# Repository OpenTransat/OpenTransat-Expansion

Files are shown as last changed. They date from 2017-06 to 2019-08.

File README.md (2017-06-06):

# OpenTransat-Expansion

The [Navigator](https://github.com/OpenTransat/OpenTransat-Navigator) is mounted on top of Expansion Board that will provide additional functions more specific to the boat. This modular design allows to make quick modifications on the Expansion Board while keeping the more complex Navigation Board unchanged.

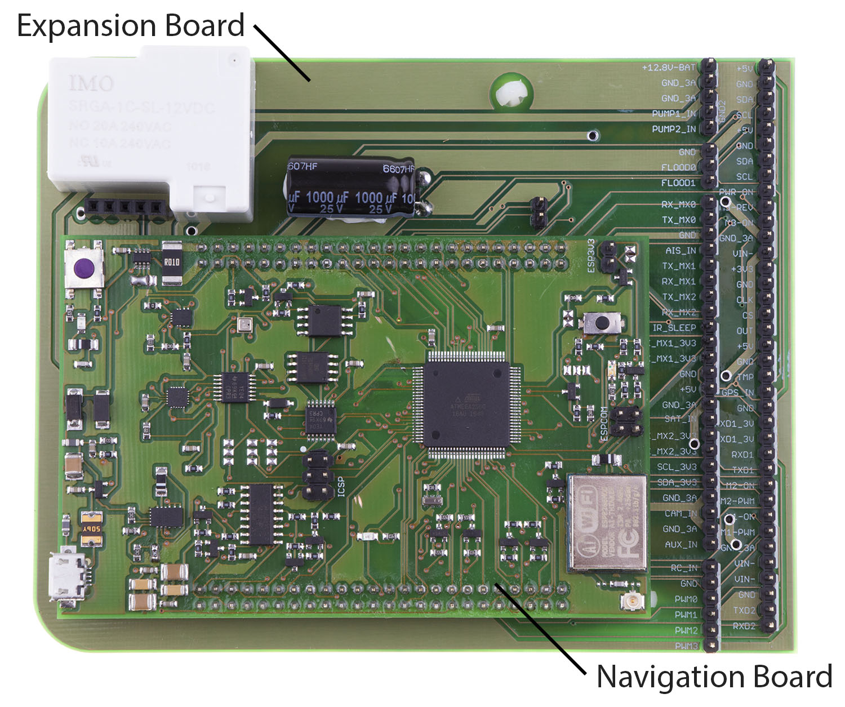
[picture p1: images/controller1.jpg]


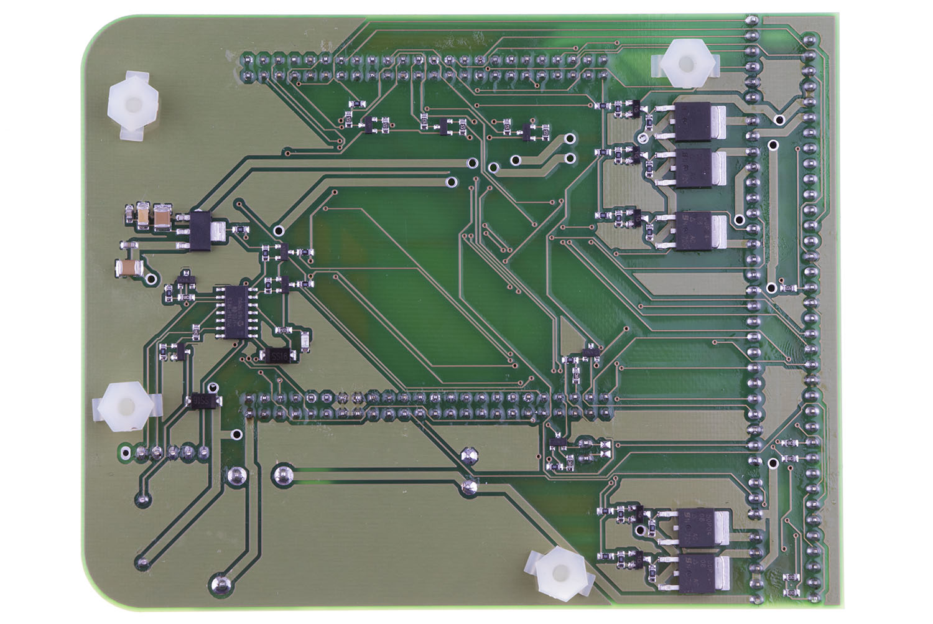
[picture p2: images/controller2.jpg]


## Features

* Watchdog timer that monitors the “heartbeat” of the main CPU. If the Navigator doesn't respond for a minute or it reports any kind of failure, the watchdog will cut power for a few seconds.

* MOSFETs to turn on particular hardware only when needed.

## Boat Hardware Scheme

Boat Hardware Scheme

Boat Hardware Scheme

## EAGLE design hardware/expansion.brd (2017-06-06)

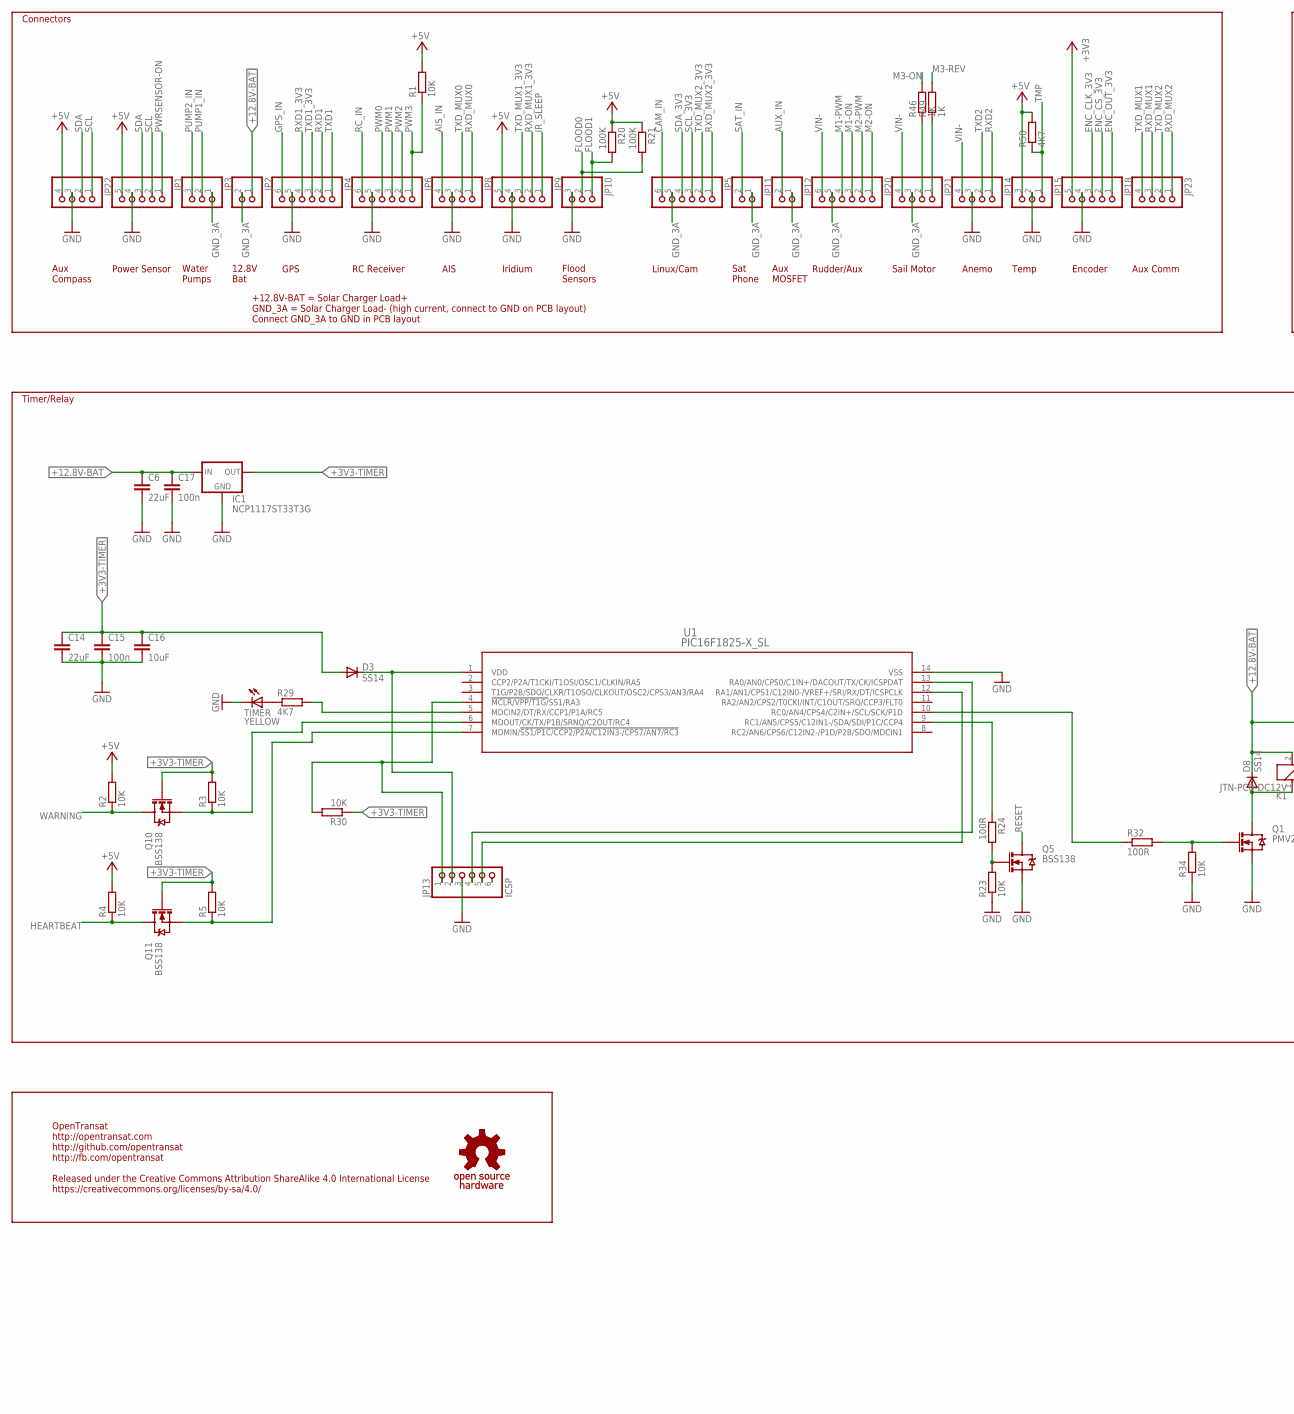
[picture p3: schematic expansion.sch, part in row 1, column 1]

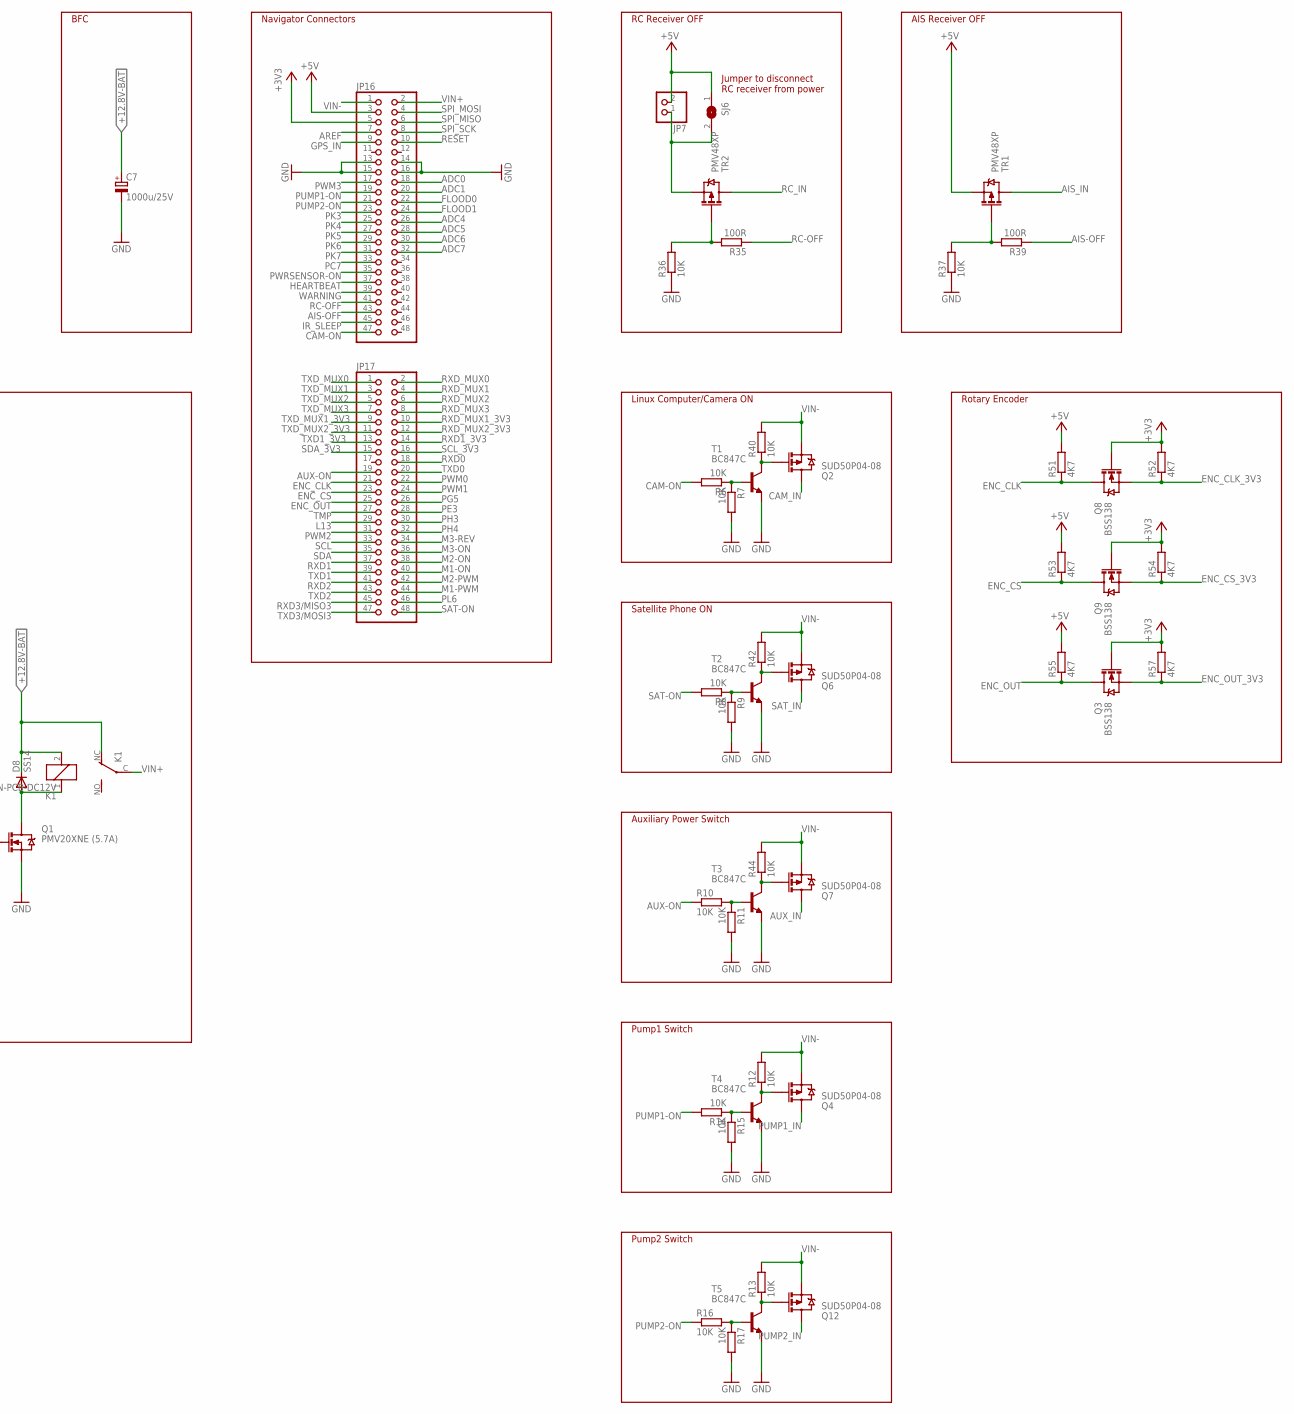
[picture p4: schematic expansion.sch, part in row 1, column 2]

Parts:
C6, C14: 22uF; C1210
C7: 1000u/25V; E5-10,5
C15, C17: 100n; C0603
C16: 10uF; C1206
D3, D8: SS14; DO214AC
IC1: NCP1117ST33T3G; SOT223
JP1, JP9, JP18: PINHD-1X5; 1X05
JP2, JP7, JP11, JP12: PINHD-1X2; 1X02
JP3, JP10, JP15: PINHD-1X3; 1X03
JP4, JP5, JP6, JP20: PINHD-1X6; 1X06
JP8, JP14, JP21, JP22, JP23: PINHD-1X4; 1X04
JP13: ICSP; 1X06
JP16, JP17: PINHD-2X24; 2X24
K1: JTN-PCB-DC12V; JT-PCB
Q1: PMV20XNE (5.7A); SOT23-3
Q2, Q4, Q6, Q7, Q12: SUD50P04-08; D-PAK_TO252AA
Q3, Q5, Q8, Q9, Q10, Q11: BSS138; SOT23-3
R1, R2, R3, R4, R5, R6, R7, R8, R9, R10, R11, R12, R13, R14, R15, R16, R17, R23, R30, R34, R36, R37, R40, R42, R44: 10K; R0603
R20, R21: 100K; R0603
R24, R32, R35, R39: 100R; R0603
R29, R50, R51, R52, R53, R54, R55, R57: 4K7; R0603
R46, R49: 1K; R0603
SJ6: SJ
T1, T2, T3, T4, T5: BC847C; SOT23
TIMER: YELLOW; CHIPLED_0805
TR1, TR2: PMV48XP; SOT23-3
U1: PIC16F1825-X_SL; SOIC14-N_MC
U$2: OSHW; OSHWM

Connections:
+3V3: JP16.5, JP18.5, Q3.1 (G), Q8.1 (G), Q9.1 (G), R52.2, R54.2, R57.2
+3V3-TIMER: C14.1, C15.1, C16.1, D3.A, IC1.2 (OUT), IC1.4 (OUT), Q10.1 (G), Q11.1 (G), R3.2, R5.2, R30.1
+5V: JP1.5, JP7.2, JP9.5, JP15.3, JP16.3, JP22.4, R1.2, R2.2, R4.2, R20.1, R21.1, R50.2, R51.2, R53.2, R55.2, SJ6.1, TR1.2 (S)
+12.8V-BAT: C6.1, C7.+, C17.1, D8.C, IC1.3 (IN), JP2.1, K1.2, K1.NC (O)
ADC0: JP16.18
ADC1: JP16.20
ADC4: JP16.26
ADC5: JP16.28
ADC6: JP16.30
ADC7: JP16.32
AIS-OFF: JP16.43, R39.1
AIS_IN: JP8.4, TR1.3 (D)
AREF: JP16.7
AUX-ON: JP17.19, R10.1
AUX_IN: JP12.2, Q7.2 (D)
CAM-ON: JP16.47, R6.2
CAM_IN: JP5.6, Q2.2 (D)
ENC_CLK: JP17.21, Q8.3 (D), R51.1
ENC_CLK_3V3: JP18.3, Q8.2 (S), R52.1
ENC_CS: JP17.23, Q9.3 (D), R53.1
ENC_CS_3V3: JP18.2, Q9.2 (S), R54.1
ENC_OUT: JP17.25, Q3.3 (D), R55.1
ENC_OUT_3V3: JP18.1, Q3.2 (S), R57.1
FLOOD0: JP10.2, JP16.22, R21.2
FLOOD1: JP10.1, JP16.24, R20.2
GND: C6.2, C7.-, C14.2, C15.2, C16.2, C17.2, IC1.1 (GND), JP1.4, JP4.5, JP6.5, JP8.3, JP9.4, JP10.3, JP13.3, JP14.3, JP15.2, JP16.13, JP16.14, JP16.15, JP16.16, JP18.4, JP22.3, Q1.2 (S), Q5.2 (S), R7.2, R9.2, R11.2, R15.2, R17.2, R23.1, R34.1, R36.1, R37.1, T1.2 (E), T2.2 (E), T3.2 (E), T4.2 (E), T5.2 (E), TIMER.C, U1.14 (VSS)
GND_3A: JP2.2, JP3.1, JP5.5, JP11.1, JP12.1, JP20.5, JP21.3
GPS_IN: JP4.6, JP16.9
HEARTBEAT: JP16.37, Q11.3 (D), R4.1
IR_SLEEP: JP9.1, JP16.45
L13: JP17.29
M1-ON: JP17.40, JP20.3
M1-PWM: JP17.44, JP20.4
M2-ON: JP17.38, JP20.1
M2-PWM: JP17.42, JP20.2
M3-ON: JP17.36, R46.2
M3-REV: JP17.34, R49.2
unnamed: R6.1, R7.1, T1.1 (B)
unnamed: Q10.2 (S), R3.1, U1.6 (MDOUT/CK/TX/P1B/SRNQ/C2OUT/RC4)
unnamed: R8.1, R9.1, T2.1 (B)
unnamed: Q11.2 (S), R5.1, U1.7 (MDMIN/!SS1/P1C/CCP2/P2A/C12IN3-/CPS7/AN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)
unnamed: R10.2, R11.1, T3.1 (B)
unnamed: Q4.1 (G), R12.1, T4.3 (C)
unnamed: Q12.1 (G), R13.1, T5.3 (C)
unnamed: R14.1, R15.1, T4.1 (B)
unnamed: R16.2, R17.1, T5.1 (B)
unnamed: JP21.2, R46.1
unnamed: JP21.1, R49.1
unnamed: JP13.4, U1.13 (RA0/AN0/CPS0/C1IN+/DACOUT/TX/CK/ICSPDAT)
unnamed: Q7.1 (G), R44.1, T3.3 (C)
unnamed: Q6.1 (G), R42.1, T2.3 (C)
unnamed: Q2.1 (G), R40.1, T1.3 (C)
unnamed: JP13.1, R30.2, U1.4 (!MCLR/VPP/T1G/!SS1/RA3)
unnamed: JP13.5, U1.12 (RA1/AN1/CPS1/C12IN0-/VREF+/SRI/RX/DT/IC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)
unnamed: R32.1, U1.10 (RC0/AN4/CPS4/C2IN+/SCL/SCK/P1D)
unnamed: D3.C, JP13.2, U1.1 (VDD)
unnamed: R24.1, U1.9 (RC1/AN5/CPS5/C12IN1-/SDA/SDI/P1C/CCP4)
unnamed: Q5.1 (G), R23.2, R24.2
unnamed: R29.2, U1.5 (MDCIN2/DT/RX/CCP1/P1A/RC5)
unnamed: R29.1, TIMER.A
unnamed: Q1.1 (G), R32.2, R34.2
unnamed: JP7.1, SJ6.2, TR2.2 (S)
unnamed: D8.A, K1.1, Q1.3 (D)
unnamed: R35.2, R36.2, TR2.1 (G)
unnamed: R37.2, R39.2, TR1.1 (G)
PC7: JP16.33
PE3: JP17.28
PG5: JP17.26
PH3: JP17.30
PH4: JP17.32
PK3: JP16.23
PK4: JP16.25
PK5: JP16.27
PK6: JP16.29
PK7: JP16.31
PL6: JP17.46
PUMP1-ON: JP16.19, R14.2
PUMP1_IN: JP3.2, Q4.2 (D)
PUMP2-ON: JP16.21, R16.1
PUMP2_IN: JP3.3, Q12.2 (D)
PWM0: JP6.4, JP17.22
PWM1: JP6.3, JP17.24
PWM2: JP6.2, JP17.31
PWM3: JP6.1, JP16.17, R1.1
PWRSENSOR-ON: JP1.1, JP16.35
RC-OFF: JP16.41, R35.1
RC_IN: JP6.6, TR2.3 (D)
RESET: JP16.10, Q5.3 (D)
RXD0: JP17.18
RXD1: JP4.2, JP17.37
RXD1_3V3: JP4.4, JP17.14
RXD2: JP14.1, JP17.41
RXD3/MISO3: JP17.45
RXD_MUX0: JP8.1, JP17.2
RXD_MUX1: JP17.4, JP23.3
RXD_MUX1_3V3: JP9.2, JP17.10
RXD_MUX2: JP17.6, JP23.1
RXD_MUX2_3V3: JP5.1, JP17.12
RXD_MUX3: JP17.8
SAT-ON: JP17.48, R8.2
SAT_IN: JP11.2, Q6.2 (D)
SCL: JP1.2, JP17.33, JP22.1
SCL_3V3: JP5.3, JP17.16
SDA: JP1.3, JP17.35, JP22.2
SDA_3V3: JP5.4, JP17.15
SPI_MISO: JP16.6
SPI_MOSI: JP16.4
SPI_SCK: JP16.8
TMP: JP15.1, JP17.27, R50.1
TXD0: JP17.20
TXD1: JP4.1, JP17.39
TXD1_3V3: JP4.3, JP17.13
TXD2: JP14.2, JP17.43
TXD3/MOSI3: JP17.47
TXD_MUX0: JP8.2, JP17.1
TXD_MUX1: JP17.3, JP23.4
TXD_MUX1_3V3: JP9.3, JP17.9
TXD_MUX2: JP17.5, JP23.2
TXD_MUX2_3V3: JP5.2, JP17.11
TXD_MUX3: JP17.7
VIN+: JP16.2, K1.C
VIN-: JP14.4, JP16.1, JP20.6, JP21.4, Q2.3 (S), Q4.3 (S), Q6.3 (S), Q7.3 (S), Q12.3 (S), R12.2, R13.2, R40.2, R42.2, R44.2
WARNING: JP16.39, Q10.3 (D), R2.1

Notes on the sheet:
Navigator Connectors
Connectors
Timer/Relay
RC Receiver OFF
AIS Receiver OFF
Linux Computer/Camera ON
Satellite Phone ON
Auxiliary Power Switch
Rotary Encoder
12.8V Bat
GPS
RC Receiver
AIS
Iridium
Flood Sensors
Linux/Cam
Sat Phone
Aux MOSFET
Rudder/Aux
Sail Motor
Anemo
Temp
Encoder
Aux Comm
+12.8V-BAT = Solar Charger Load+ GND_3A = Solar Charger Load- (high current, connect to GND on PCB layout) Connect GND_3A to GND in PCB layout
Water Pumps
BFC
OpenTransat http://opentransat.com http://github.com/opentransat http://fb.com/opentransat Released under the Creative Commons Attribution ShareAlike 4.0 International License https://creativecommons.org/licenses/by-sa/4.0/
Jumper to disconnect RC receiver from power
Pump1 Switch
Pump2 Switch
Aux Compass
Power Sensor

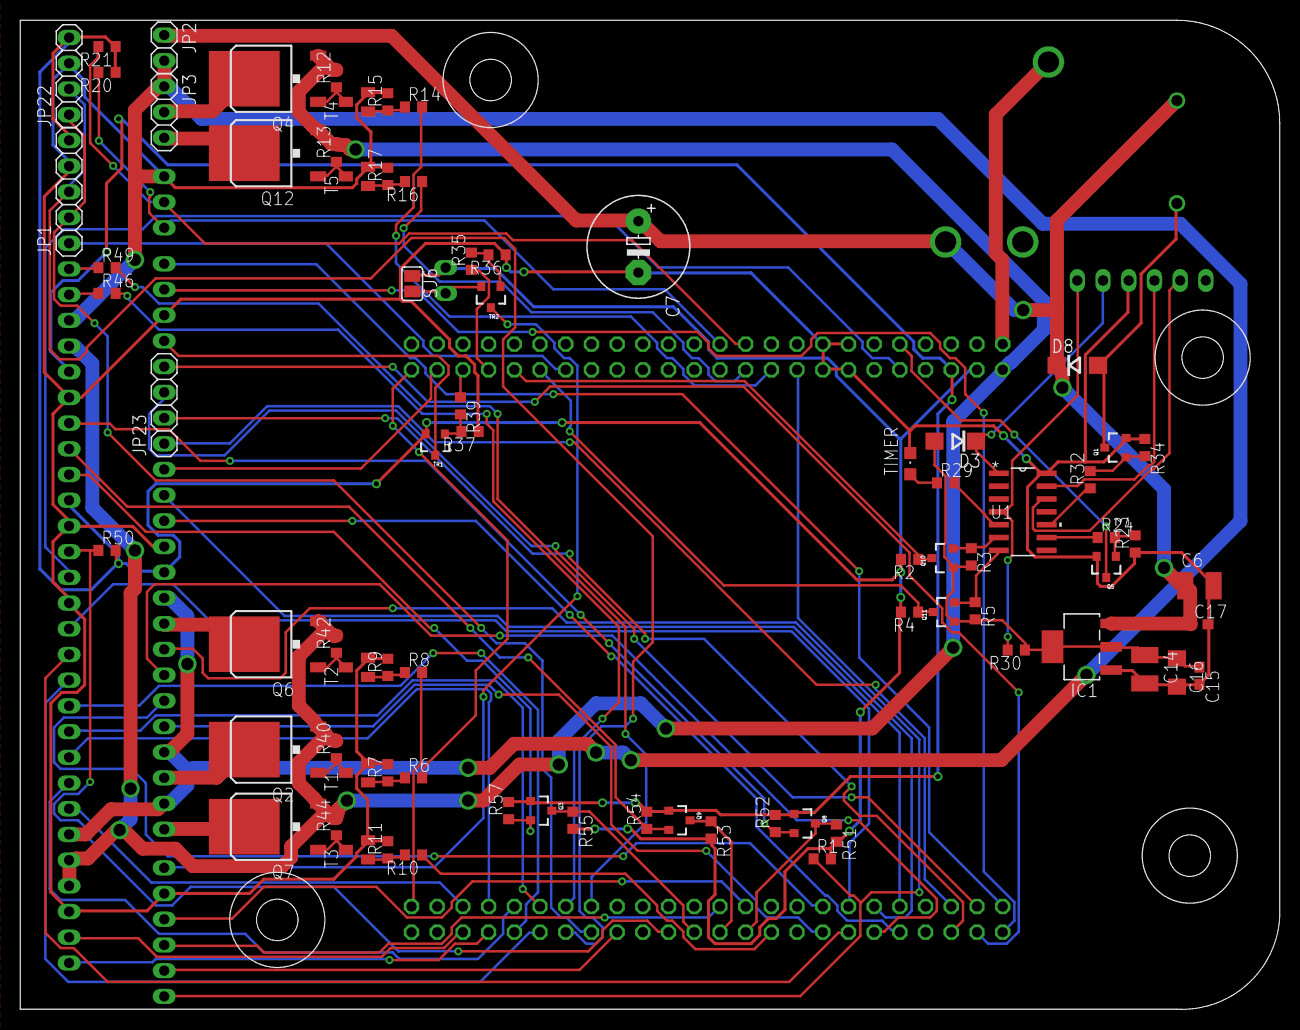
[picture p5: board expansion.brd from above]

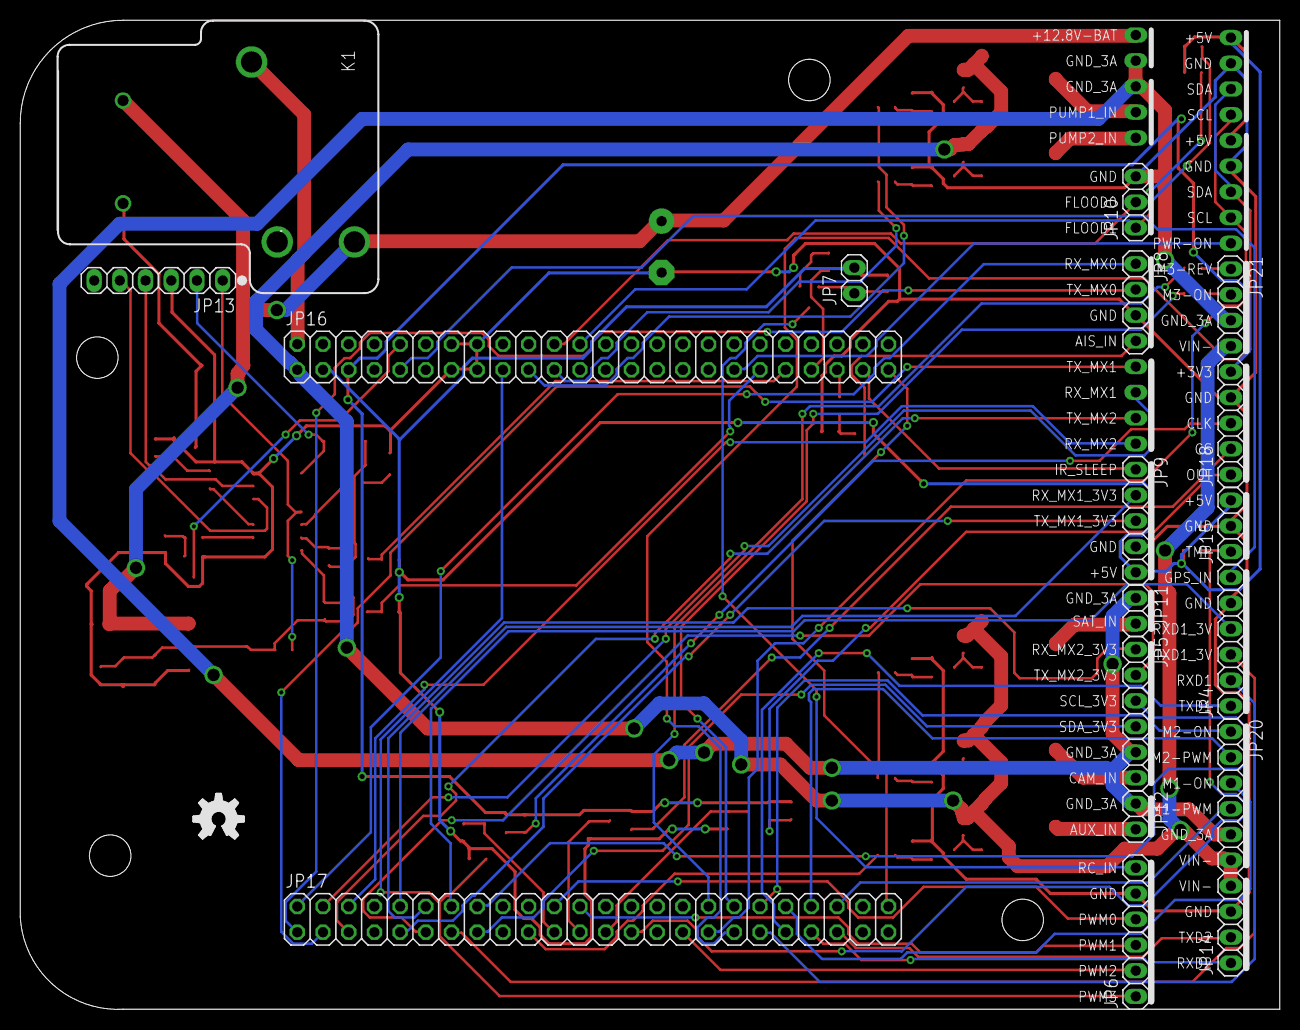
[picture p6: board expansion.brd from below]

Board: 2 copper layers, 124.5 x 97.7 mm, 96 parts (18 on the bottom side), 95 nets.

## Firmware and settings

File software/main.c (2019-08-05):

/*
Hardware watchdog timer based on PIC16F1825

OpenTransat
http://opentransat.com
http://github.com/opentransat
http://fb.com/opentransat

Released under the Creative Commons Attribution ShareAlike 4.0 International License
https://creativecommons.org/licenses/by-sa/4.0/
*/

#define _XTAL_FREQ 31000UL
#include "config.h"
#include <xc.h>

#define RELAY PORTCbits.RC0
#define NAVRESET PORTCbits.RC1
#define HEARTBEAT PORTCbits.RC3
#define WARNING PORTCbits.RC4
#define LED PORTCbits.RC5

#define TMR1INIT (65535 - 31000) //timer1 increments +31000 per second

#define RESET_AFTER_SEC 60 //reset after no heartbeat
//#define RESET_AFTER_SEC 15 //TESTING reset after no heartbeat

#define RELAY_AFTER_SEC 24UL*3600UL //periodically turn off the whole boat
//#define RELAY_AFTER_SEC 60 //TESTING periodically turn off the whole boat

#define WARNING_SEC 30 //WARNING pin LOW a number of seconds before relay shutdown

#define RESET_US 200

#define RELAY_SEC 15 //turn off time, discharge all capacitors
//#define RELAY_SEC 10 //TESTING turn off time, discharge all capacitors

volatile unsigned long sectimer1, sectimer2; //incrementing each second in timer1 interrupt

void init_io() {
    OSCCONbits.IRCF = 0b0000; //31kHz oscillator
    TRISA = 0;
    PORTA = 0;
    TRISC = 0b00001000; //RC0 = RELAY (active high), RC1 = NAVRESET (active high), RC3 = HARTBEAT (input), RC4 = WARNING (active low), RC5 = LED (active high)
    PORTC = 0b00010000;
    
    //timer1 for detecting heartbeat
    T1CONbits.TMR1CS = 0b01; //increment on Fosc
    T1CONbits.T1CKPS = 0b00; //prescaler 1:1
    T1CONbits.TMR1ON = 1;
    
    //enable interrupts for timer1
    PIR1bits.TMR1IF = 0; //interrupt flag should be cleared before enabling interrupts (page 195 http://ww1.microchip.com/downloads/en/DeviceDoc/41440A.pdf)
    PIE1bits.TMR1IE = 1;
    INTCONbits.PEIE = 1;
    INTCONbits.GIE = 1;

    //disable all analog ports
    ANSELA = 0;
    ANSELC = 0;

    //disable some peripherals
    CM1CON0bits.C1ON = 0;
    CM2CON0bits.C2ON = 0;
    RCSTAbits.SPEN = 0;    
}

void delay_sec(unsigned int n) {
    while (n--) {
        CLRWDT();
        LED = LED?0:1;
        __delay_ms(1000);
    }
}

void navreset() {
    NAVRESET = 1;
    __delay_us(RESET_US);    
    NAVRESET = 0;
}

void relay_reset(unsigned int sec) {
    RELAY = 1;
    delay_sec(sec);
    RELAY = 0;
}

void interrupt timer1_interrupt(void) {
    if(PIR1bits.TMR1IF && PIE1bits.TMR1IE) {
        sectimer1++;
        sectimer2++;
        TMR1 = TMR1INIT;
        PIR1bits.TMR1IF = 0;
    }
}

void main(void) {

    init_io();

    char hb, hb_prev;
    sectimer1 = 0;
    sectimer2 = 0;
    TMR1 = TMR1INIT;
    
    while(1) {
        CLRWDT();
        
        hb = HEARTBEAT;

        if (hb != hb_prev) { //heartbeat detected: reset sectimer1
            sectimer1 = 0;
            LED = 1;
            __delay_ms(10);
            LED = 0;
        }
        
        if (sectimer1 > RESET_AFTER_SEC) { //no heartbeat: reset master CPU (no warning)
            navreset();
            sectimer1 = 0;
            LED = 1;
            __delay_ms(10);
            LED = 0;
        }
        
        if (sectimer2 > RELAY_AFTER_SEC) { //relay shutdown every RELAY_AFTER_SEC seconds
            WARNING = 0;
            delay_sec(WARNING_SEC);
            relay_reset(RELAY_SEC);
            WARNING = 1;
            __delay_ms(100);
            navreset();
            sectimer1 = 0;
            sectimer2 = 0;
            LED = 1;
            __delay_ms(10);
            LED = 0;
        }
        
        hb_prev = hb;

    }
    return;
}
